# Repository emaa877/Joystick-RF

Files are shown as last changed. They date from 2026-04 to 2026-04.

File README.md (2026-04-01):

El sistema permite el control remoto de actuadores (como servos o robots) mediante un enlace inalámbrico de baja latencia.

---

## Imágenes

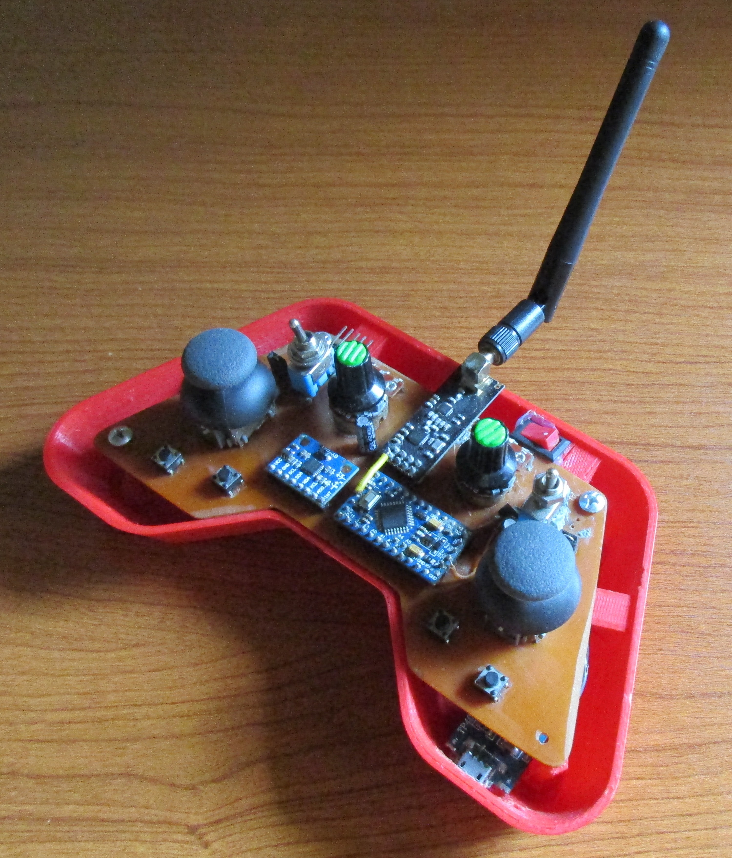
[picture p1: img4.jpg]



---

## Características principales

- Comunicación inalámbrica 2.4 GHz con nRF24L01
- Alimentación portátil con baterías 18650
- Programación en bajo nivel usando AVR Studio
- Lectura de 2 joystick analógico (ejes XY + botón)
- Envío de múltiples variables en tiempo real
- Diseño mecánico propio (carcasa personalizada)

---

## Descripción del sistema

El sistema está compuesto por dos módulos:

### Transmisor (Joystick)
- Lee valores analógicos del joystick (X, Y)
- Detecta estado de botón
- Envía datos vía nRF24L01

### Receptor
- Recibe los datos inalámbricos
- Controla actuadores (servo, robot, etc.)

El módulo nRF24L01 opera en la banda de 2.4 GHz con tasas de hasta 2 Mbps y alcance típico de ~100 m en espacio abierto :contentReference[oaicite:0]{index=0}.

---

## Hardware utilizado

### Transmisor
- Arduino Pro Mini (ATmega328P)
- Módulo nRF24L01
- Joystick analógico (2 ejes + botón)
- Batería 18650
- Regulador de voltaje (step-down a 3.3V / 5V)
- Switch de encendido
- PCB / protoboard

### Receptor
- Arduino (Uno / Nano / Pro Mini)
- Módulo nRF24L01
- Servo motor / Motor paso a paso (ver [Proyecto de Microcontroladores](https://github.com/emaa877/Microcontroladores)

---

## Conexión del nRF24L01

El módulo utiliza comunicación SPI:

| nRF24L01 | Arduino Pro Mini |
|---|---|
| VCC | 3.3V |
| GND | GND |
| CE | D7 |
| CSN | D8 |
| SCK | D13 |
| MOSI | D11 |
| MISO | D12 |

Importante:
- NO alimentar con 5V
- Se recomienda capacitor (10µF–100µF) entre VCC y GND para estabilidad

---

## Alimentación (Batería 18650)

El sistema es portable gracias a una batería 18650:

- Voltaje nominal: 3.7V
- Uso de módulo step-up/down según configuración
- Protección recomendada (BMS)

Configuración típica:
- 18650 → Regulador → 5V (Arduino)
- 18650 → Regulador → 3.3V (nRF24L01)

---

## Software

### Entorno
- AVR Studio (Atmel Studio)
- Programación en C/C++ sin abstracciones Arduino

### Librerías
- SPI (implementación AVR)
- RF24 (adaptada para AVR)

---

## Comunicación inalámbrica

El sistema utiliza:
- Protocolo SPI para comunicarse con el módulo
- Direcciones ("pipes") para transmisión
- Comunicación bidireccional opcional

Ejemplo conceptual:

```c
typedef struct {
    uint16_t joyX;
    uint16_t joyY;
    uint8_t button;
} DataPackage;

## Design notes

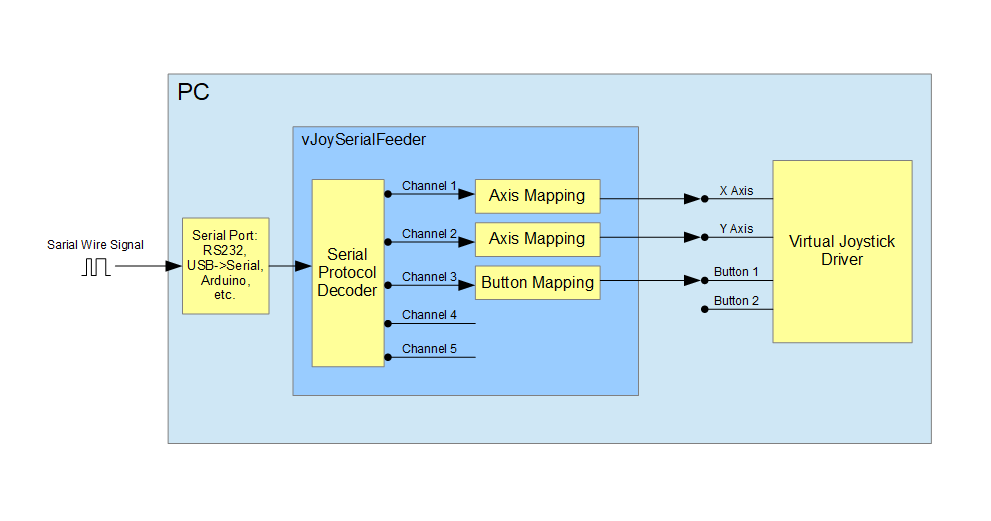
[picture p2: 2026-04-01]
vJoySerialFeeder-1.5/Docs/images/overview-diagram.png

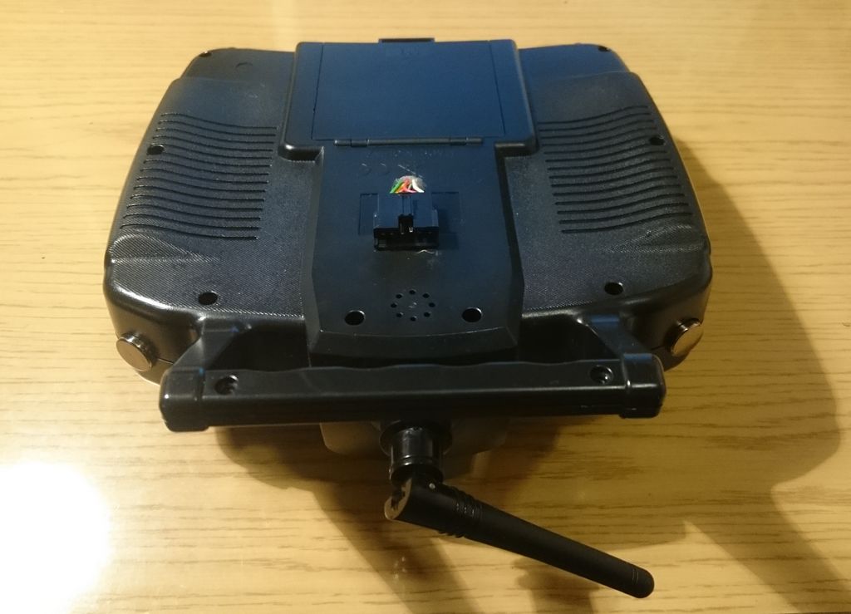
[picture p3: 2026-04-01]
vJoySerialFeeder-1.5/Docs/images/ard3.jpg

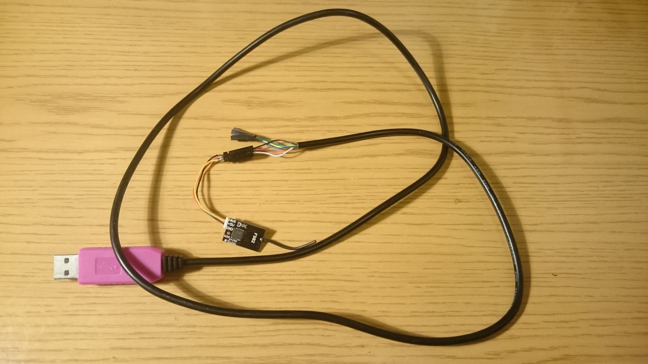
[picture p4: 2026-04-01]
vJoySerialFeeder-1.5/Docs/images/flysky.jpg

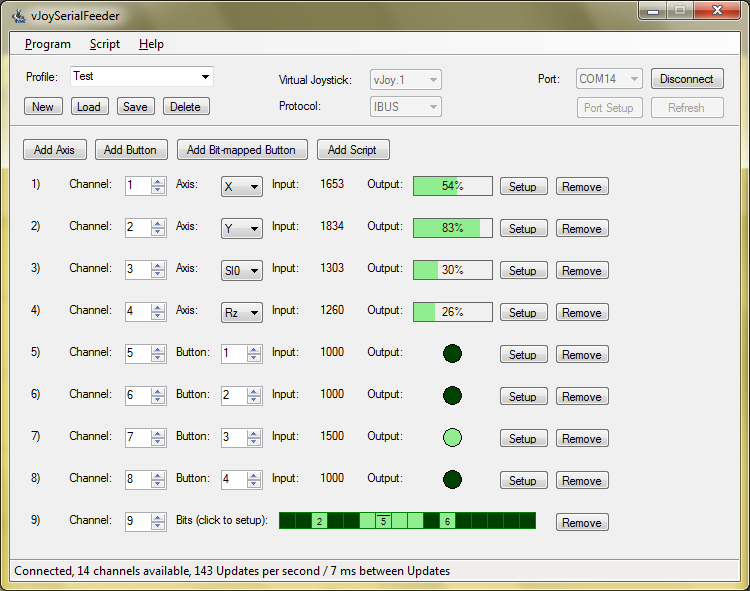
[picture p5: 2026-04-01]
vJoySerialFeeder-1.5/Docs/images/screenshot.png

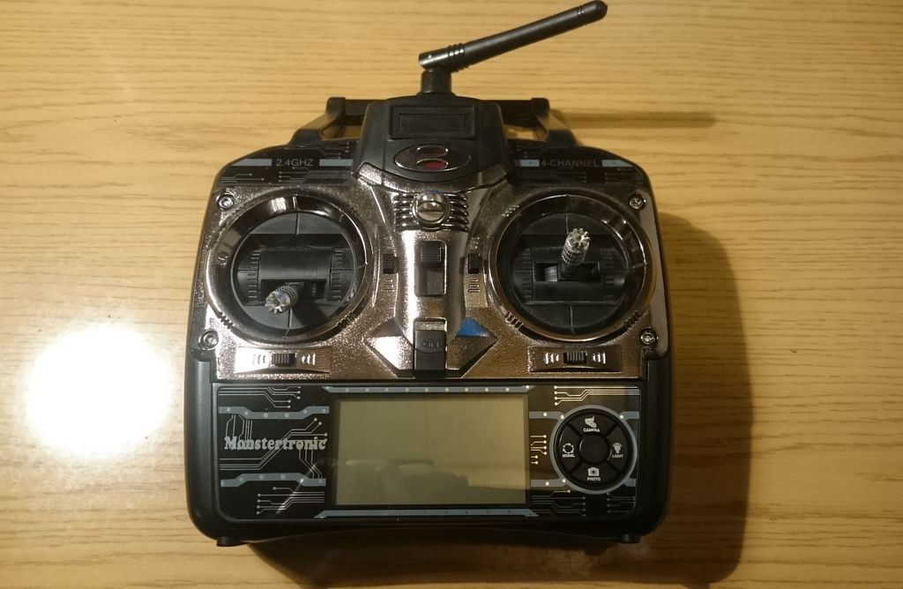
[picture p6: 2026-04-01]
vJoySerialFeeder-1.5/Docs/images/ard1.jpg

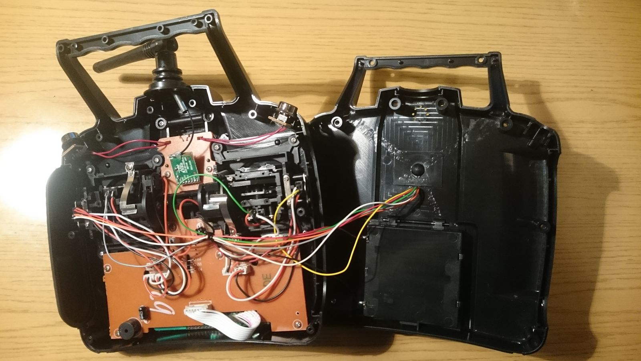
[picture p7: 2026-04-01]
vJoySerialFeeder-1.5/Docs/images/ard2.jpg

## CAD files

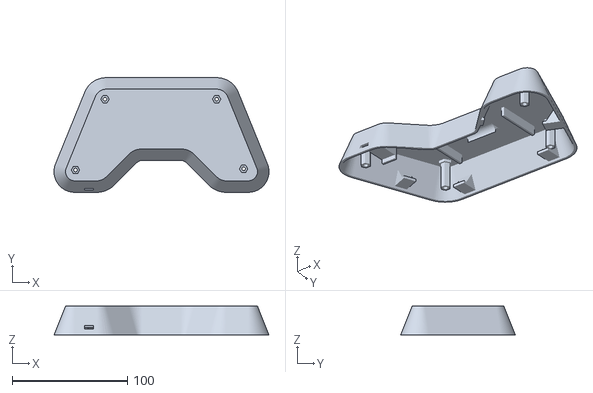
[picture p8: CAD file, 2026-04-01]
Back2 Joystick v9.stl
186.9 x 99.7 x 25.0

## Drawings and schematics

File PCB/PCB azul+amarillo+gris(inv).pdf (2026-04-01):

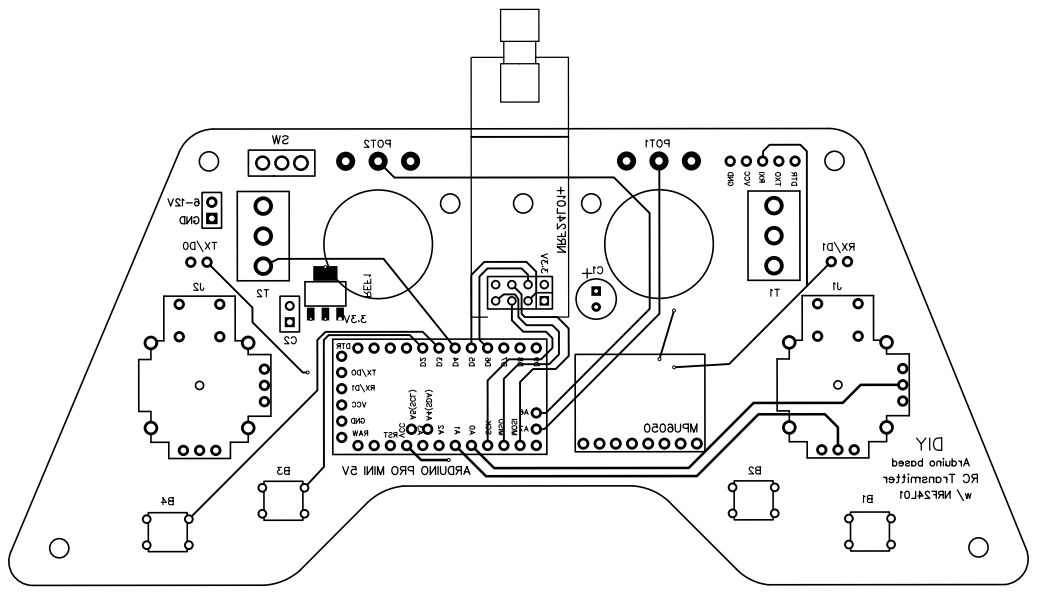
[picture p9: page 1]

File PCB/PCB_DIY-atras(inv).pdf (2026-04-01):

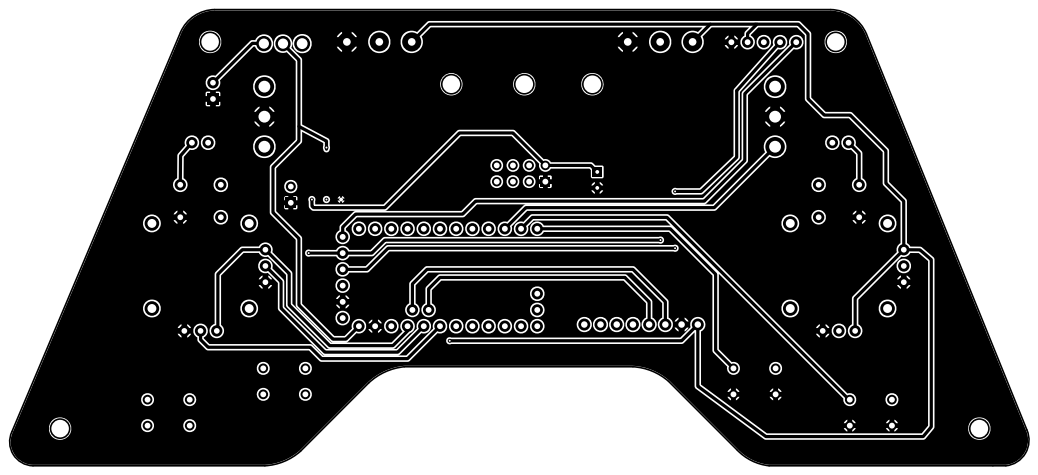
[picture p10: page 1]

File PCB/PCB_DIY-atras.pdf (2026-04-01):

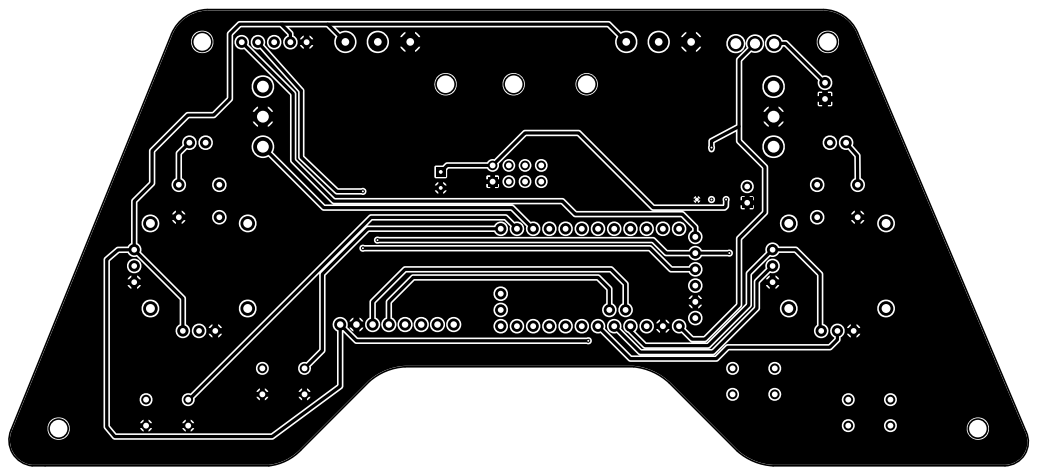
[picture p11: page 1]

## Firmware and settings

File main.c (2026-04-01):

#define ARDUINO 2 //1: Arduino UNO, 2: ARDUINO PRO-MINI

#include "main.h"
#include "nrf24l01.h"

uint8_t ADC_Read(uint8_t adc_to_read);

struct NRF24{
	uint8_t PRX_PTX;
	uint8_t addr;
	uint8_t channel;
	uint8_t state;
	uint8_t payload[BUFFER_SIZE];
};
struct NRF24 nrf24;

int main(void){
	nrf24.PRX_PTX = PTX;  //PTX
	nrf24.addr = 0x01;    //es de 5bytes. Sera address x5, cada byte igual
	nrf24.channel = 0x6E; //110 -> 2510 MHz
	
	PUD_OFF; //bit para activar las resistencias pull-up
	B1_INPUT; B2_INPUT; B3_INPUT; B4_INPUT; S1_INPUT; S1_INPUT;
	B1_PULL_UP; B2_PULL_UP; B3_PULL_UP; B4_PULL_UP; S1_PULL_UP; S2_PULL_UP;
			
	SS_OUTPUT;
	SPI_pin_setup();
	config_SPI_Master(0, 16); //modo=0 (polaridad 0, fase 0) y prescaler= 16 
	
	cli();
	NRF24L01_config(nrf24.PRX_PTX, nrf24.addr, nrf24.channel); 
	sei();
		
	while (1){
		nrf24.payload[0] = ADC_Read(1); //Se leen los 8 MSB
		nrf24.payload[1] = ADC_Read(0);
		nrf24.payload[2] = ADC_Read(2);
		nrf24.payload[3] = ADC_Read(3);
		nrf24.payload[4] = ADC_Read(7);
		nrf24.payload[5] = ADC_Read(6);
		
		nrf24.payload[6]  = B1_TEST ? 1 : 0; //entradas digitales con pull-up, 0: presionadas, 1:sin presionar
		nrf24.payload[7]  = B2_TEST ? 1 : 0;
		nrf24.payload[8]  = B3_TEST ? 1 : 0;
		nrf24.payload[9]  = B4_TEST ? 1 : 0;
		nrf24.payload[10] = S1_TEST ? 1 : 0;
		nrf24.payload[11] = S2_TEST ? 1 : 0;
			
		transmit_payload(nrf24.payload, BUFFER_SIZE);	
		reset_IRQ();
		_delay_ms(20); 
	}
}

uint8_t ADC_Read(uint8_t adc_to_read){
	uint8_t ADC_value;
	ADMUX = adc_to_read;                     //configuro el canal
	SETBIT(ADMUX, REFS0);                    //AREF
	SETBIT(ADMUX, ADLAR);                    //resolucion 10 bits alineado a izq
	
	SETBITS(ADCSRA, 3);                      //prescaler en 8
	SETBIT(ADCSRA, ADEN);                    //habilitamos el ADC
	SETBIT(ADCSRA, ADSC);                    //inicia la conversion

	while(ADCSRA & (1 << ADSC));             //espera a que finalice la conversion

	ADC_value = ADCH;                        //8 MSB
	return ADC_value;
}

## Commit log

2026-04-01 Upload project
    [Back2 Joystick v9.stl, Pots.fzz]
2026-04-01 Update actuator description in README
    Corrected the spelling of 'Imgágenes' to 'Imágenes' and updated the description of the controlled system to include 'Motor paso a paso'.
